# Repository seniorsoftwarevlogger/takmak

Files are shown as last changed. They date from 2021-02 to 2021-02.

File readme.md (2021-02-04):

65% orthogonal staggered column split keyboard
==

You may not use this for any commercial purpose.

Video
--

Вводное видео (https://www.youtube.com/watch?v=OgppSAD-pnE "Вводное видео")

Layout
--

http://www.keyboard-layout-editor.com/#/gists/c3e709013b8413fe901a2af3728c1977

Components
--

2 x Pro Micros  
2 x TRRS breakouts  
71 x Chery MX compatible switches  
71 x 1N4148 diodes  
Wires

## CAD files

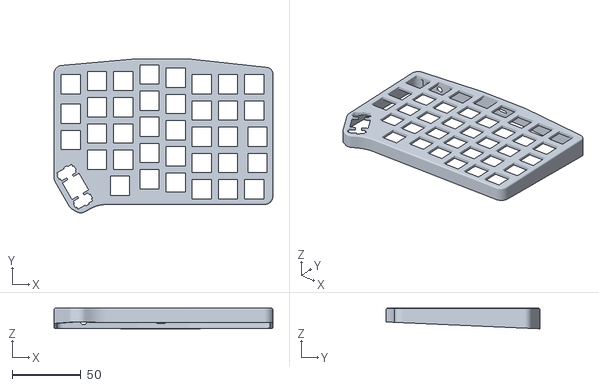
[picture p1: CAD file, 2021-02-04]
3d models/SSV_Split - Right.stl
159.1 x 111.9 x 15.0

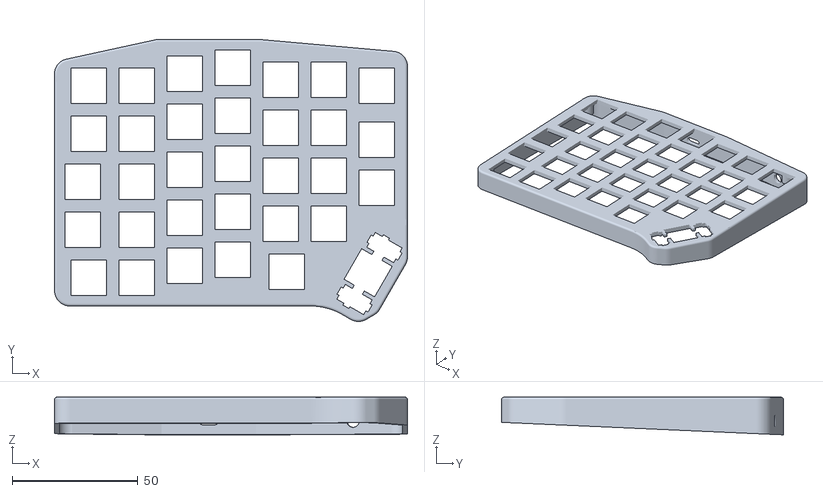
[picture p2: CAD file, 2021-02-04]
3d models/SSV_Split - Left.stl
140.1 x 111.9 x 15.0

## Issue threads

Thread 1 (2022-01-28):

Будешь ли ты проектировать плату под клавиатуру?

aldecode, 2022-01-28:
Будешь ли ты проектировать плату под клавиатуру и делиться?)

nLight, 2022-01-31:
Уже в пути

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

aldecode, 2022-01-31:
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

Можно gerber?)

nLight, 2022-01-31:
Пока нет. Надо проверить.

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

aldecode, 2022-08-22:
Есть какой-то апдейт по этому?)

nLight, 2022-08-23:
Вариант работает с одним исправлением, но я его уже переделал и надо
проверить новую версию.

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

CoffeeAddictGuy, 2022-12-20:
Привет, плохо понимаю в платах
Можешь подсказать, где на плате место для диодов? Всматриваюсь и никак понять не могу(

nLight, 2022-12-20:
пару примеров указал

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

nLight, 2022-12-20:
Платы залиты в реп, кстати

CoffeeAddictGuy, 2022-12-21:
Тогда ещё вопросик, направление диодов любое?
Или в каком направлении их припаивать?
Диоды 1N4742A-12V
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

nLight, 2022-12-21:
Черной головкой (катодом) к квадрату.

CoffeeAddictGuy, 2022-12-25:
Привет, ещё вопрос
Можно ли использовать данные место под подключение LED диодов?
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

nLight, 2022-12-25:
LED не предполагались. Это доп отверстия под разные свичи. Поэтому нельзя.

Closed 2022-12-20.

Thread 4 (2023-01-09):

Контроллер к плате

CoffeeAddictGuy, 2023-01-09:
Привет, из разметки на плане не совсем понятно какой стороной крепить ATmega32U4 к плате, я креплю к задней стороне платы, но не понимаю ATmega32U4 крепить лицевой стороной в сторону стола или к плате? (лицевая сторона это видно распниновку и тд)
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

CoffeeAddictGuy, 2023-01-09:
Если не сложно и сохранились можешь скинуть свою готовую и спаенную плату дабы был референс

Closed 2023-01-25.

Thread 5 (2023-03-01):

Левая клавиатура некорректная раскладка

CoffeeAddictGuy, 2023-03-01:
После сборки клавиатуры правая часть клавиатуры работает корректно, а у левой некорректная раскладка, где должен быть Esc нажимается 3 и так вниз, конфиг полностью брал из вашего репозитория для тестирования
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
Чуть скорректировал саму раскладку, её прикладываю
[takmak_error.zip](https://github.com/seniorsoftwarevlogger/takmak/files/10863907/takmak_error.zip)

В чём может быть проблема? Не сталкивались с таким
Пробовал прошивать одной прошивкой оба модуля, пробовал очищать от прошивки левый контроллер, всё равно некорректно

CoffeeAddictGuy, 2023-03-02:
Если проблема повторяется у кого-то, то требуется в config.h убрать SPLIT_USB_DETECT, далее в config.h заревёрсить MATRIX_COL_PINS
Чтобы было вот так
#define MATRIX_ROW_PINS { D1, D0, B3, B2, B6  }
#define MATRIX_COL_PINS { C6, D4, D7, F5, F6, F7, B1, B5}

Также пустые кнопки вида XXXXXXX, требуется перенести с левых крайних на правую крайнюю, пример https://pastebin.com/6isat2TA

Также хочу заметить, что конфиг QMK и корпус для 3D принтера не подходит к плате, на плате до сих пор длинный шифт на правой клавиатуре, хотя в конфигах и модельке там его нет, просто класс

Closed 2023-03-02.

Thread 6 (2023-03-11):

Некорректные платы

w0rng, 2023-03-11:
Здравствуйте!

Кажется, на правой части клавиатуры одна кнопка не совпадает с корпусом (на корпусе на месте нее находится 2 клавиши)

Также почему-то не совпадают отверстия под arduino с отверстием под type-c разъем.

Про левую часть клавиатуры ничего сказать не могу, потому что по ошибке заказал 2 правых.

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

CoffeeAddictGuy, 2023-03-14:
Так и есть)
Видимо STL корпус не обновлял в репе, неприятно конечно от такого
Также хочу заметить что стандартные хот свапы не подходят под эту плату, так что не заказывай
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

Но подходят вот такие
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

На левой также есть проблема с отверстием под usb-c

CoffeeAddictGuy, 2023-03-14:
Если будешь всё таки собирать, то глянь мою закрытую проблему с прошивкой QMK, скорее всего у тебя такая же проблем-ка будет)

CoffeeAddictGuy, 2023-03-16:
Даже интересно будет выложена корректная версия STL для правой клавиатуры или всё таки костыльными способами придётся редактировать самому 🤔

CoffeeAddictGuy, 2023-03-18:
@w0rng Привет, подкорректировал правую часть
Я довольно плох не в художественном моделировании поэтому не обессудьте)
Заодно скидываю Blender проект чтобы можно было самому скорректировать что надо

[Keyboard_Takmak_3D.zip](https://github.com/seniorsoftwarevlogger/takmak/files/11008372/Keyboard_Takmak_3D.zip)

CoffeeAddictGuy, 2023-03-19:
Быстро фикс, на правой клавиатуре шифт слишком высоко, попробую сегодня завтра распечатать скорректированную и если норм будет то отпишу и приложу blend файл)

CoffeeAddictGuy, 2023-03-23:
Прикладываю корректную версию правой клавиатуры и сам проект
[takmak-new.zip](https://github.com/seniorsoftwarevlogger/takmak/files/11045655/takmak-new.zip)

hk2281, 2024-03-30:
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
@CoffeeAddictGuy подскажи в твоем исправленном варианте который находится на втором изображении нет углубления как в оригинальном варианте будет ли это критично при сборке или все собирается как надо? Без разницы по высоте меду правой и левой половинкой клавиатуры.

CoffeeAddictGuy, 2024-03-30:
@hk2281
Привет, если ты про стенки, то у меня проблем никаких с этим не было, разница только в том, что в одном варианте у тебя кейкапы будут уходить в глубь и будут скрываться за стенками, а во втором у тебя считай скелетон версия)

wu-n, 2024-07-11:
> @hk2281 Привет, если ты про стенки, то у меня проблем никаких с этим не было, разница только в том, что в одном варианте у тебя кейкапы будут уходить в глубь и будут скрываться за стенками, а во втором у тебя считай скелетон версия) И то, сделал это только потому что не хотел тратить лишние часы на полировку модели после печати, потому что если оставлять стенки, то придётся печатать и подпорки

@CoffeeAddictGuy  hi, is the latest model validated? can be used for pcb?

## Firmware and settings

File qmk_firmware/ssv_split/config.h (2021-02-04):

#pragma once

#include "config_common.h"

/* USB Device descriptor parameter */
#define VENDOR_ID       0xFEED
#define PRODUCT_ID      0x6060
#define DEVICE_VER      0x0001
#define MANUFACTURER    SeniorSoftwareVlogger
#define PRODUCT         SSV_Split

/* key matrix size */

/**
 * Rows are doubled-up
 *
 * https://www.reddit.com/r/olkb/comments/829ubq/rows_and_columns_of_split_using_2_pro_micros/
 *
 * The reason why the rows are doubled up instead of columns is due to the way the keyboard matrix is scanned.
 * It scans one row at a time. What the slave does it scan its rows and passes it to the master.
 * The master then stores all the row data together by virtually stacking the rows of the left
 * half on top of the right half.
 *
 * A macro remaps the stacked rows to the correct layout later on.
 */
#define MATRIX_ROWS 10
#define MATRIX_COLS 8

/* key matrix pins */
#define MATRIX_ROW_PINS { F4, F5, F6, F7, B1  }
#define MATRIX_COL_PINS { D1, D0, D4, C6, D7, E6, B4, B5}
#define MATRIX_ROW_PINS_RIGHT { F4, F5, F7, F6, B1 }
#define MATRIX_COL_PINS_RIGHT { B5, B4, E6, D7, C6, D4, D0, D1 }

/* COL2ROW or ROW2COL */
// COL2ROW means the black mark on your diode is facing to the rows, and between the switch and the rows.
#define DIODE_DIRECTION COL2ROW

/* number of backlight levels */
// #define BACKLIGHT_PIN B5

#ifdef BACKLIGHT_PIN
#define BACKLIGHT_LEVELS 3
#endif

#define SOFT_SERIAL_PIN D2
#define SPLIT_USB_DETECT

/* Set 0 if debouncing isn't needed */
#define DEBOUNCING_DELAY 5

#define MASTER_RIGHT

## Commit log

2022-02-03 Add PCB matrix
2022-02-03 move ESC instead of CAPS
2022-11-13 Add gerber files
    [Takmak-left-B_Cu.gbr, Takmak-left-B_Mask.gbr, Takmak-left-B_Paste.gbr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]
2022-11-14 Add low profile case
    [Takmak - left bottom.stl, Takmak - left top.stl, Takmak - right bottom.stl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]
2026-10-11 Build Takmak website with interactive keyboard scene and assembly downloads
2026-10-11 Collect current CAD, KiCad and local QMK sources
2026-10-11 Add English site and persistent RU/EN language switch
2026-11-04 fix(oled): balance portrait typography and spacing
    Use one 8x8 monospace font, regular row and group spacing, symmetric margins,
    and a crisp 8x8 lightning icon. Remove the divider while preserving battery
    readings and disconnect handling.
    Update the RU/EN site, guides, rendered preview and release manifest for the
    exact flashed v0.1.1 UF2. Preserve v0.1.0 for rollback.
    Validation: real LVGL and Zephyr mono rendering, all battery values 0..100,
    rotation and disconnect tests with ASan/UBSan; firmware build and flash;
    site build, published-path checks, and UI review at 1440/390/320 px in RU/EN.
